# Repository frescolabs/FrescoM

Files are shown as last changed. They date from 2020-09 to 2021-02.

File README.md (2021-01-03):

# FrescoM

Steps to reproduce the project:

1. Order parts from the hardware/components folder
2. 3D print needed parts from the hardware/sources folder
3. Install firmware to your Arduino from the firmware folder
4. Connect your computer with Arduino via serial
5. Install software from software folder

Please file an issue if somthing is not clear.

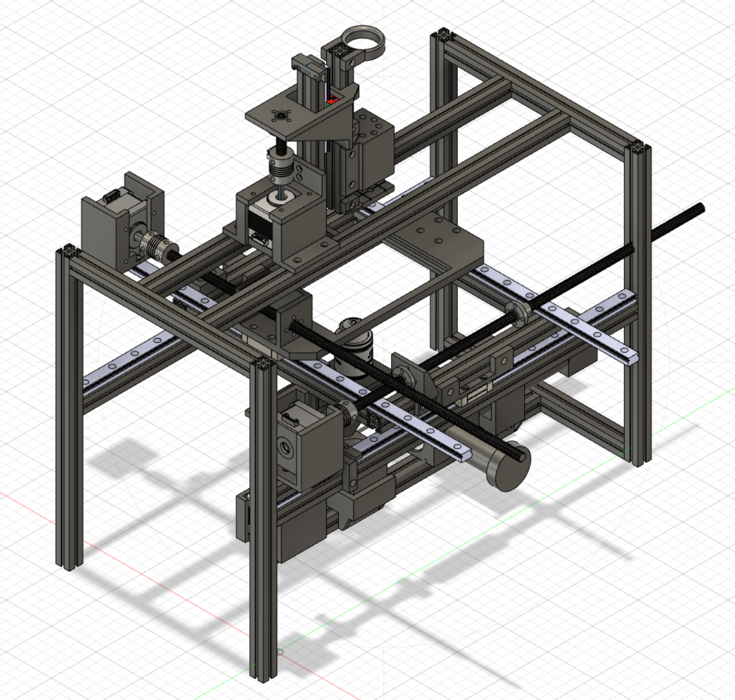
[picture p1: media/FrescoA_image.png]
alt frescoa


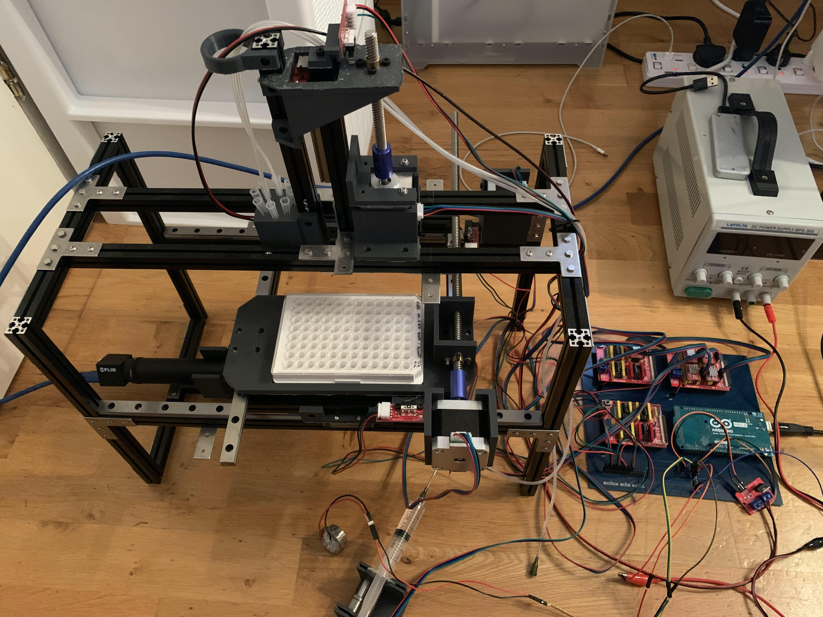
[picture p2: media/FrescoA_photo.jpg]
alt frescoa photo


alt frescoa photo

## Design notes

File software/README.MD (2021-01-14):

# Logic and UI for Fresco

## Set up the project

download anaconda and install conda

run script from "software" folder to install conda environment and some libraries: python 3.8

```bash condainstall.sh```

```conda activate fresco-env  ```

install pip packages for your platform:

```pip install -r mac.txt```

or

```pip install -r windows.txt```

or 

```pip install -r linux.txt```

run

```python main.py```

## Set up in the UI

1. Align top left well with the objective and run "Remember top left position" command

2. Align bottom right well with the objective and run "Remember bottom right position" command

3. Run sync plate coordinates button

![alt frescoa photo](https://github.com/frescolabs/FrescoM/blob/master/media/FrescoA_ux.png?raw=true)

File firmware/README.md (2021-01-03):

Firmware:

Arduino Mega:

You need arduino editor to run it

See all available serial commands here:
https://github.com/frescolabs/FrescoM/blob/master/firmware/FrescoMFirmware/Command.h

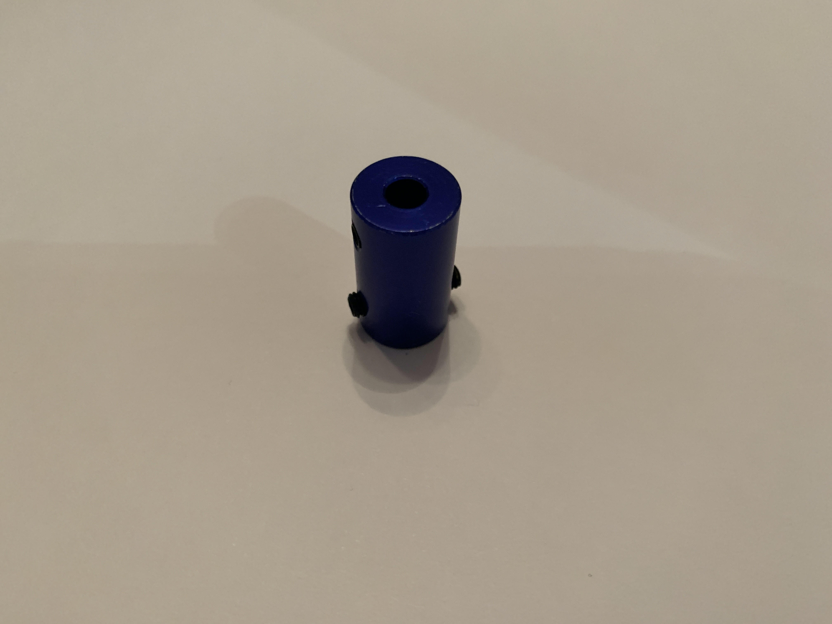
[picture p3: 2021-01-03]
media/Nema_17_adapter.jpg

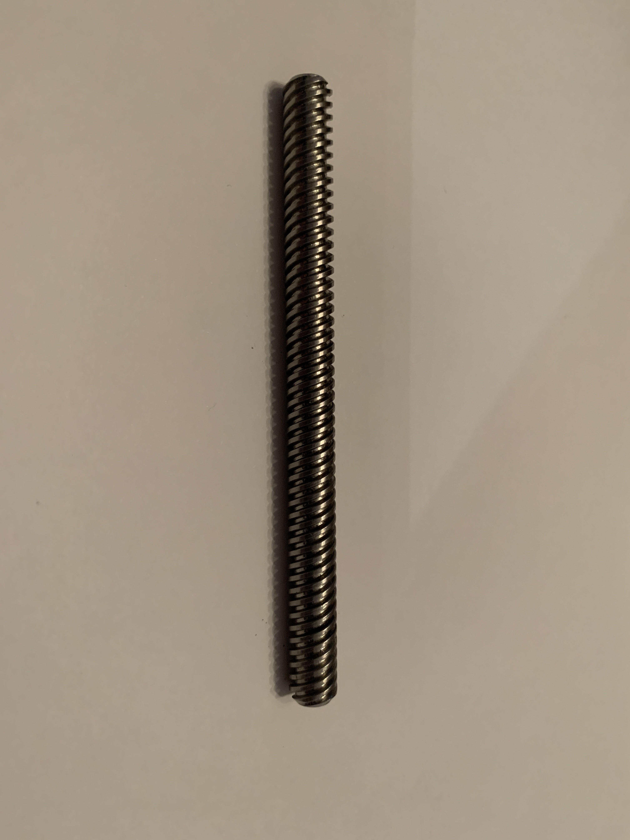
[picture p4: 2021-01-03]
media/Screw.jpg

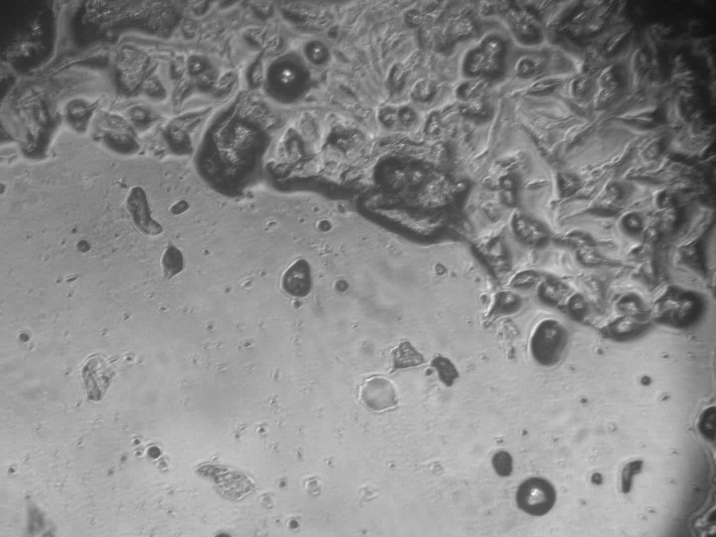
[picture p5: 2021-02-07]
software/1_corner_0.png

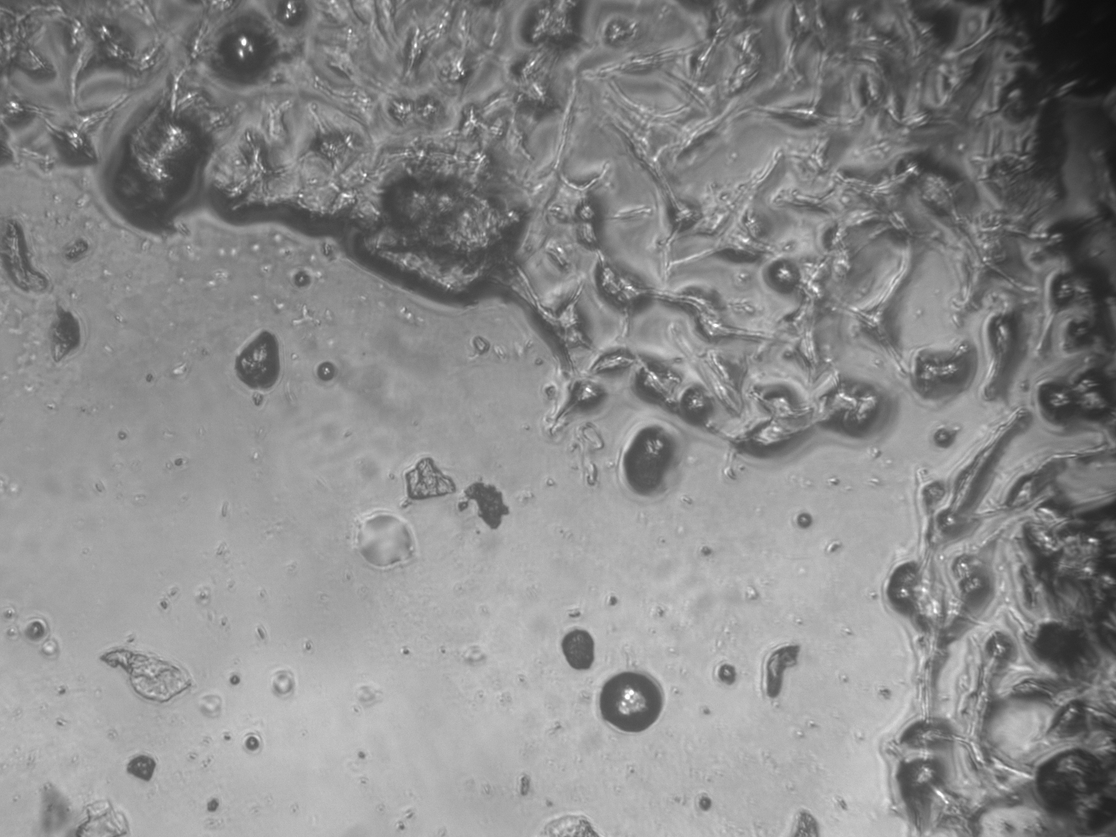
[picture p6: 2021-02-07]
software/1_corner_9.png

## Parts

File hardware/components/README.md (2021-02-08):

List of components for the Hardware part

1. 12  Nema 17 Stepper Motors (+- 22 GBP). 
https://www.amazon.co.uk/Stepper-13N-cm-Holding-Printer-craftsman168/dp/B07H5C5943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

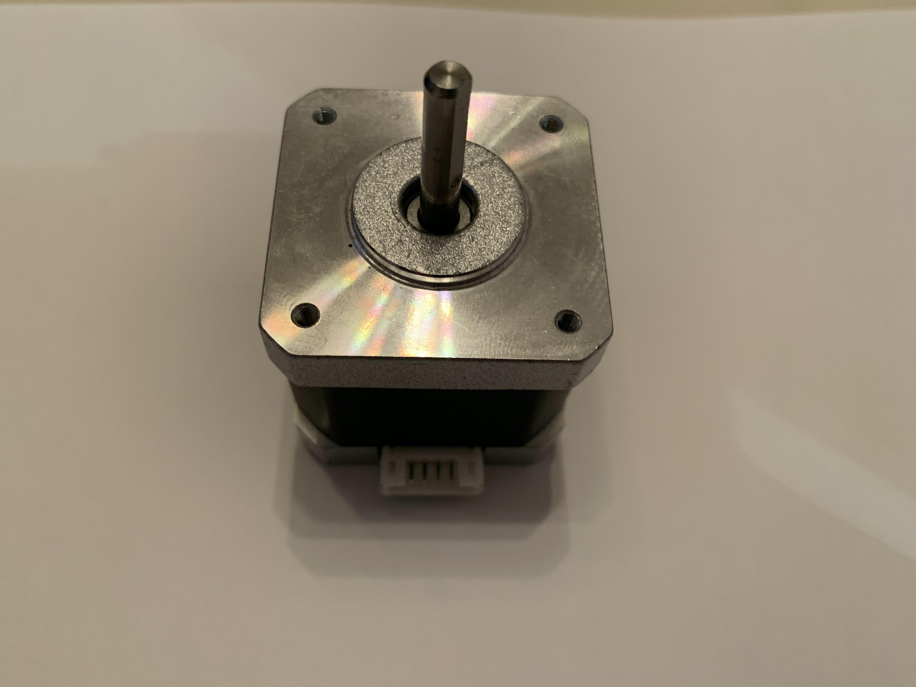
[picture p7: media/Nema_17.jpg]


2. Two 400 mm Linear Guide Rails (+- 44 GBP):
https://www.amazon.co.uk/Miniature-Linear-LML12H-Printer-Machine/dp/B07KK83Y8B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

3. Three 250 mm Linear Guide Rails (+- 44 GBP):
https://www.amazon.co.uk/Accurate-Linear-Guide-Professional-Technical/dp/B07LDBNVTW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

4. One 100 mm Linear Guide Rails
https://www.amazon.co.uk/belupai-100-1000mm-Linear-MGN12H-Sliding/dp/B083LV5PLN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

5. 9 250 mm Screw Rod with Nut (+- 11 GBP).  
https://www.amazon.co.uk/Screw-250mm-Printer-Threaded-Linear/dp/B06WP1WZSY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

6. One 400 mm Screw Rod with Nut (+- 11 GBP):
https://www.amazon.co.uk/Screw-250mm-Printer-Threaded-Linear/dp/B06WRN1DQS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

7. 12 Nema 17 Driver A4988 (+- 13 GBP): 
https://www.amazon.co.uk/Stepper-Stepstick-Headsink-Arduino-Machines/dp/B07B9ZKST7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

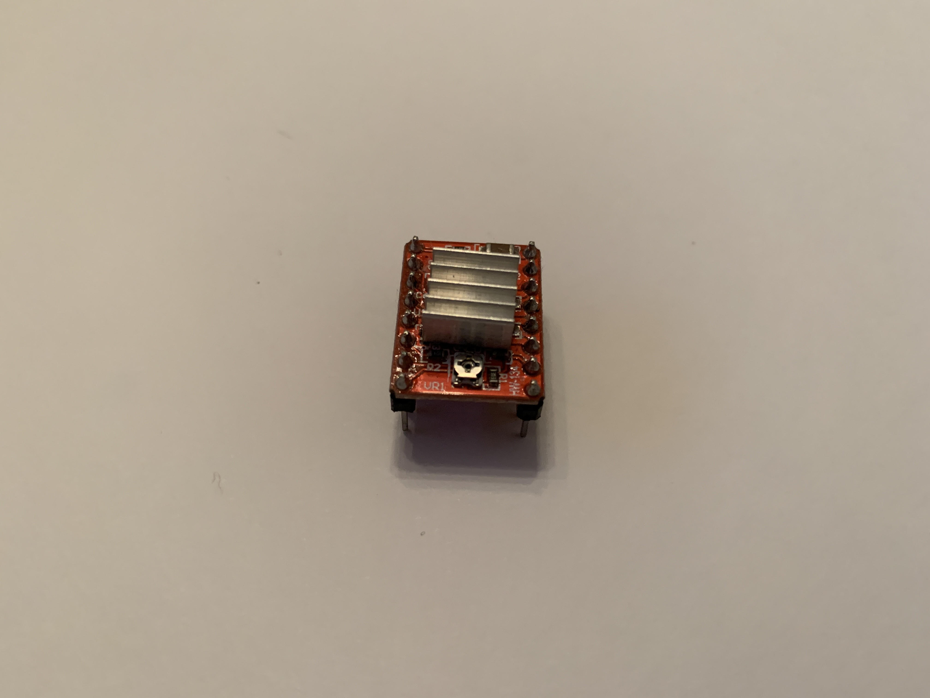
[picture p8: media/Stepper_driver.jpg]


8. 12 Mini Limit Switch 3 pins (+- 8 GBP):
https://www.amazon.co.uk/KingYH-Momentary-Instrument-Communications-Electronic/dp/B07YDFBS5X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

9. One Arduino Mega (+- 42 GBP):
https://www.amazon.co.uk/ARDUINO-MEGA-2560-REV3-A000067/dp/B0046AMGW0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

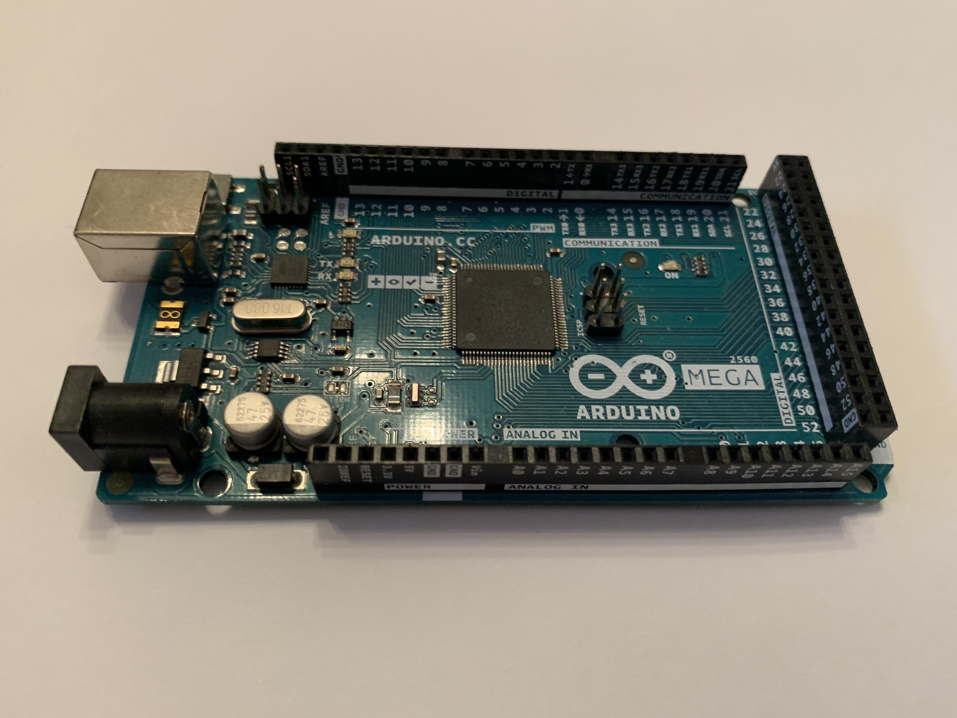
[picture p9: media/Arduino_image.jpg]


10. M3x8/10/15mm Screw and Nut Kit (+- 5 GBP):
https://www.amazon.co.uk/CONNEX-DP8500055-Machine-Screw-Nut/dp/B00B22VHPC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

11. Three CNC shield 
https://www.amazon.co.uk/ARCELI-Engraver-Printer-Expansion-Arduino/dp/B07CQRPFFW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

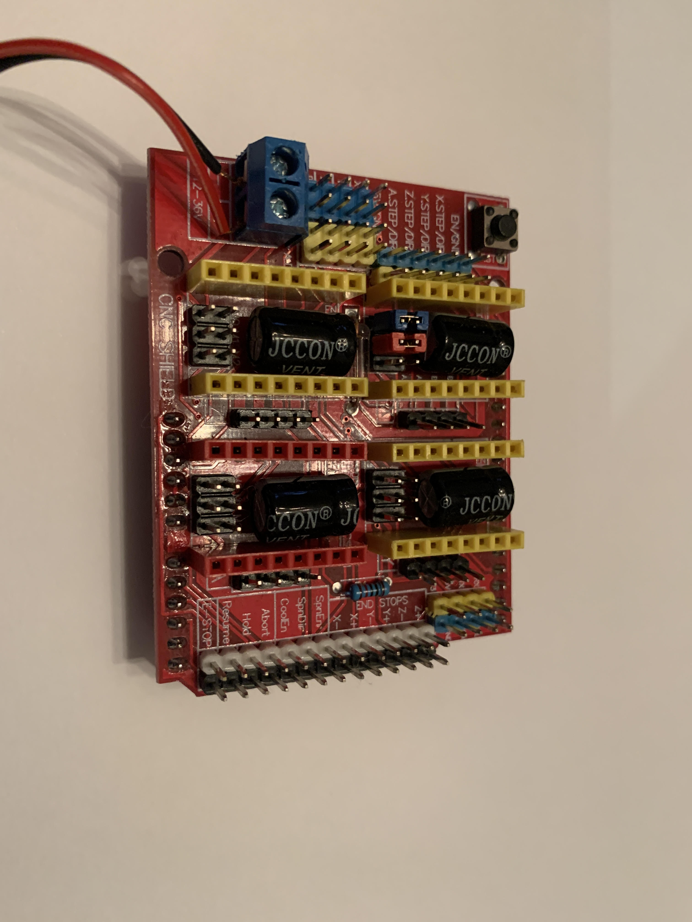
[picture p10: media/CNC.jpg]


12. 8mm mounted bearing
https://www.amazon.co.uk/DealMux-FL08-Self-aligning-Flange-Bearing/dp/B01EZZP2QC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

13. PCB (see Katunin et al. paper)

14. 3d printed components

15. LM8UU linear bearing
https://www.amazon.co.uk/s?k=LM8uu&ref=nb_sb_noss_2

16. 8mm rods
https://www.amazon.co.uk/sourcing-map-Lathe-Round-Length/dp/B07KT3MXV6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

17. 1 X IRF520 MOSFET (+- 3 GBP)
https://www.amazon.co.uk/HCMODU0083-IRF520-MOSFET-Driver-Module/dp/B012ATHAN8

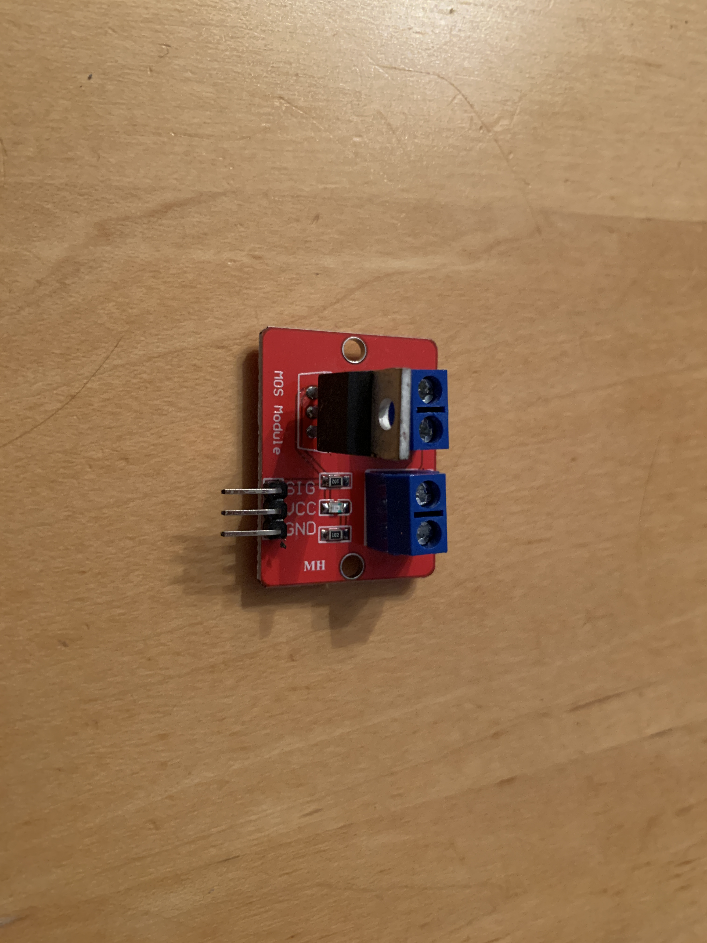
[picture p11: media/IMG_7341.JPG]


18. 1 X RCD-24 Constant Current LED Driver (6 pins)
https://uk.rs-online.com/web/p/led-driver-ics/0472222/

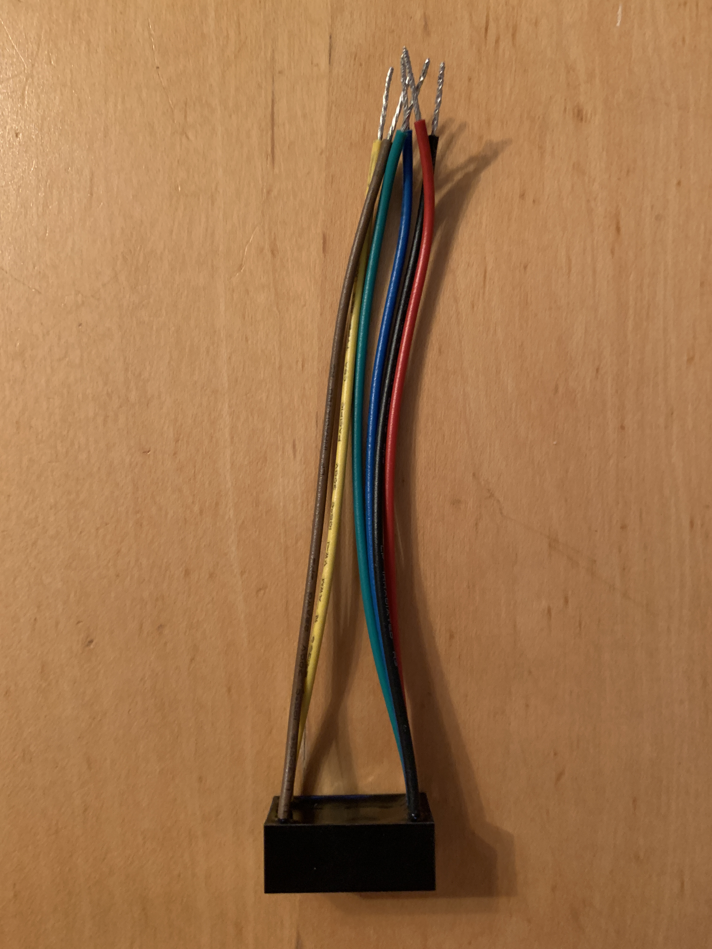
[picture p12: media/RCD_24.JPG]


19. 4 X White LED 3V (+- 5 GBP)
https://www.amazon.co.uk/gp/product/B07FCR8W2H/ref=ppx_yo_dt_b_search_asin_title?ie=UTF8&psc=1

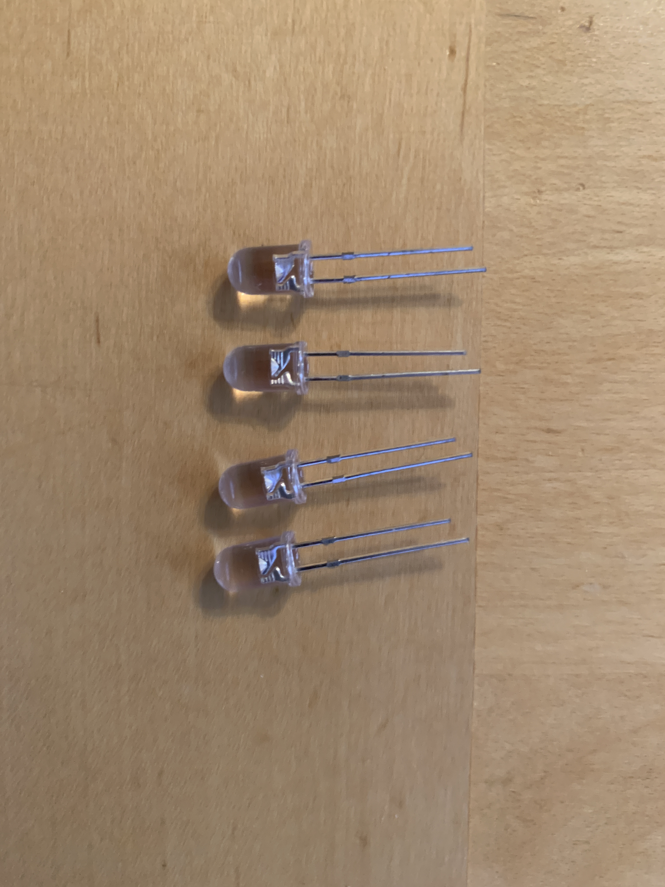
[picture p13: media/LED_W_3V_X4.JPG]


20. MakerBeam XL (+- 111 GBP)
https://www.amazon.co.uk/gp/product/B06XHXJSVL/ref=ppx_yo_dt_b_search_asin_title?ie=UTF8&psc=1

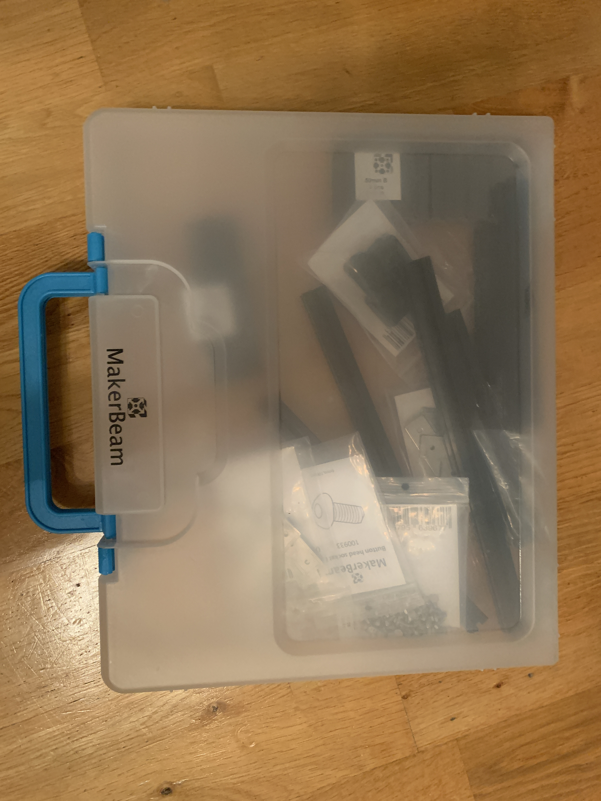
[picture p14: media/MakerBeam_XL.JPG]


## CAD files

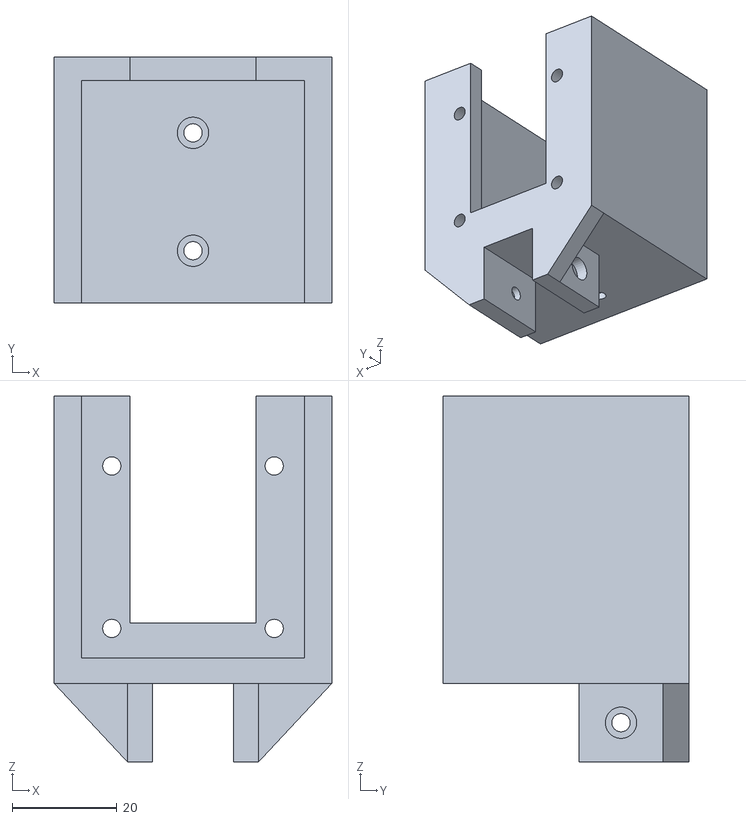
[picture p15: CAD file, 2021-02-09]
hardware/print/x_nema_holder.stl
53.0 x 47.0 x 69.9

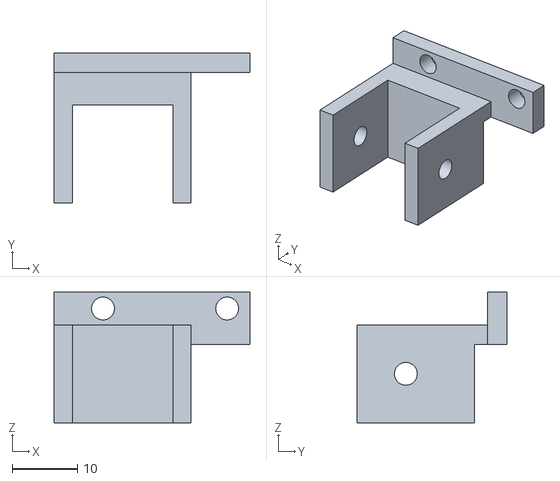
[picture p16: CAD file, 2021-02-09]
hardware/print/z_stopper_holder.stl
30.0 x 23.0 x 20.0

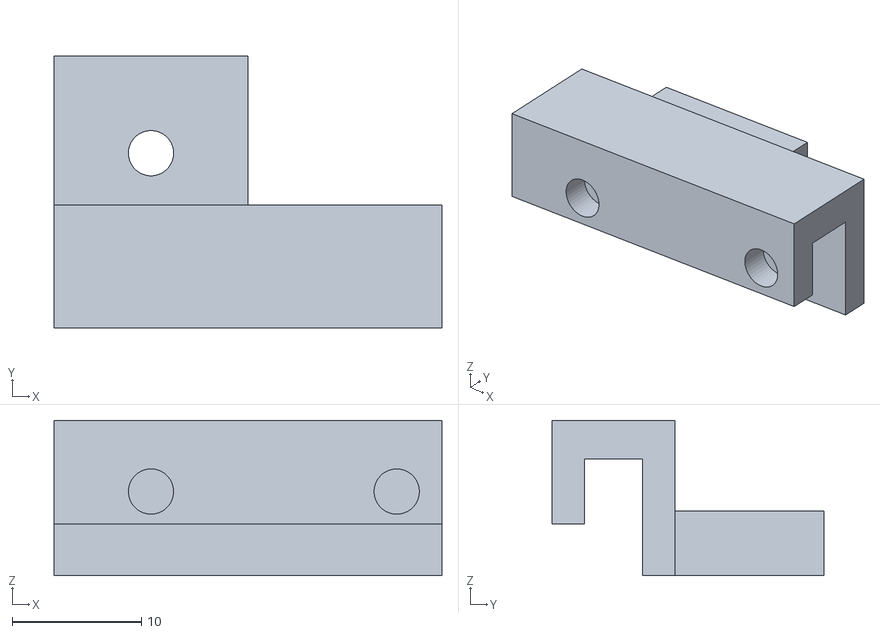
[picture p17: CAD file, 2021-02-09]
hardware/print/manifold_stopper_holder.stl
30.0 x 21.0 x 12.0

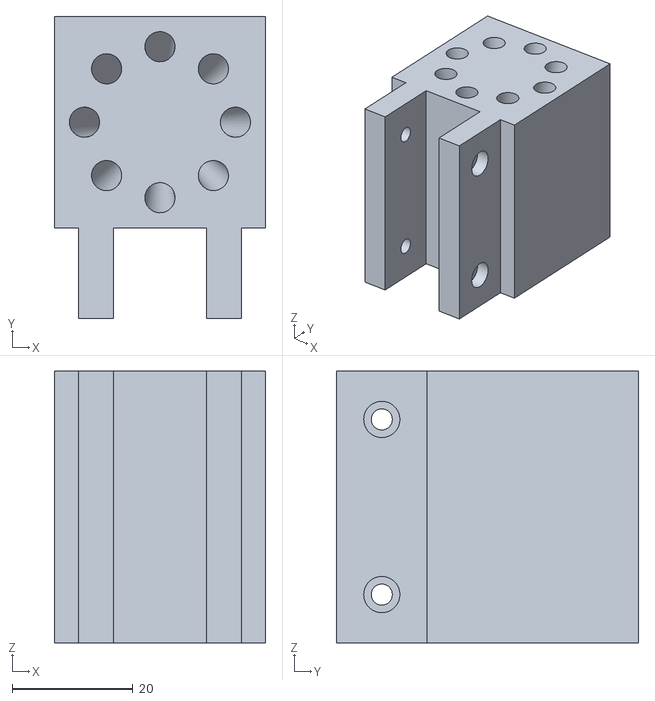
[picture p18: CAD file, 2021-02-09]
hardware/print/manifold_nozels_holder.stl
35.0 x 50.0 x 45.0

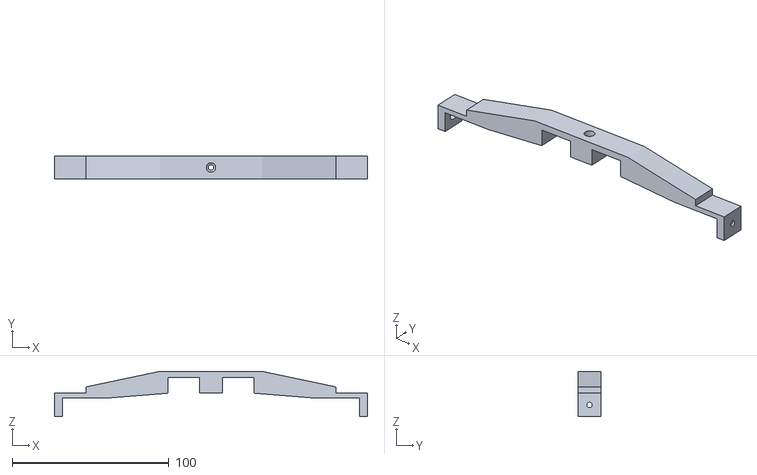
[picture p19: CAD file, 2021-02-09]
hardware/print/z_stabilizer.stl
200.0 x 15.0 x 29.0

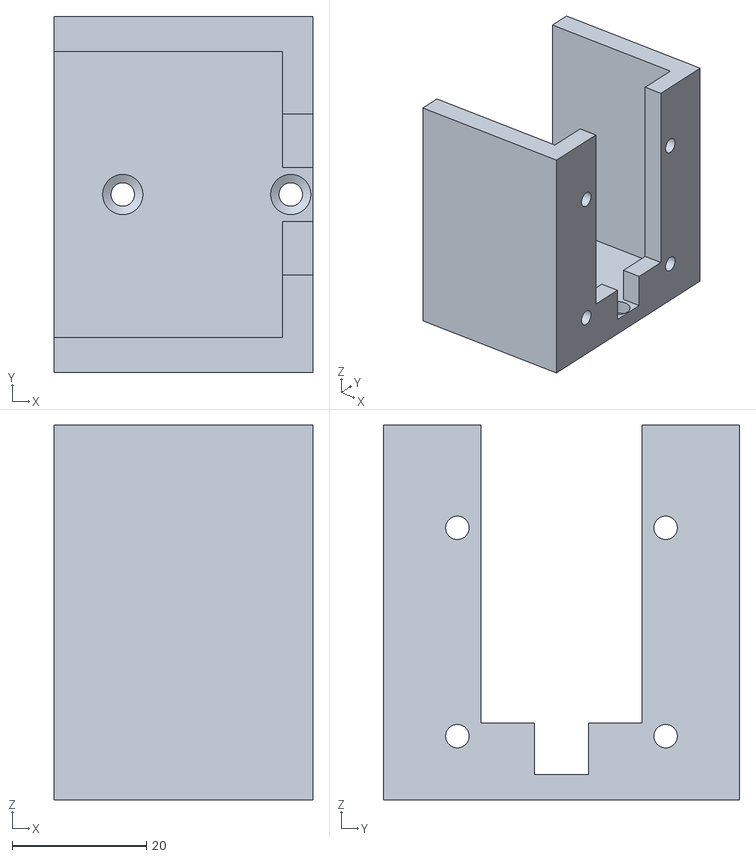
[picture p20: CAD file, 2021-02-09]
hardware/print/y_nema_holder.stl
38.5 x 53.0 x 55.8

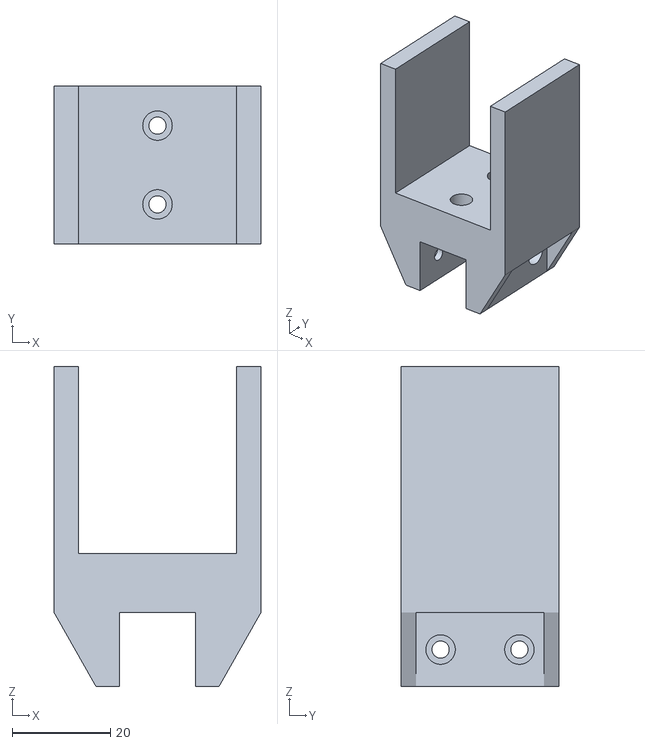
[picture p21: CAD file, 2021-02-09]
hardware/print/microscope_holder.stl
42.0 x 32.0 x 65.0

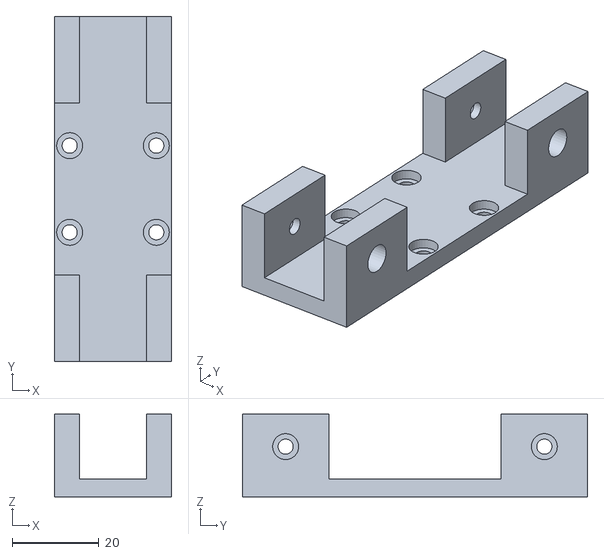
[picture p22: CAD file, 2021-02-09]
hardware/print/y_extrusion_holder_right.stl
27.0 x 79.7 x 19.1

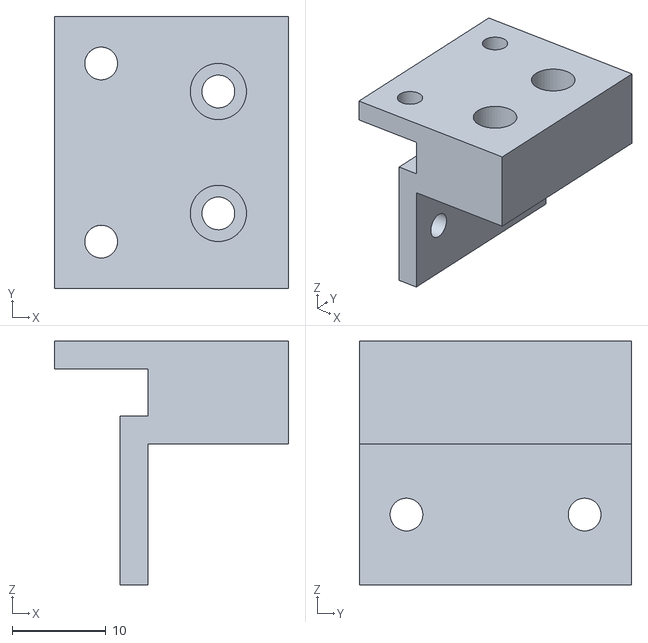
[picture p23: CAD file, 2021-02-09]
hardware/print/y_stopper_holder.stl
25.0 x 29.0 x 26.0

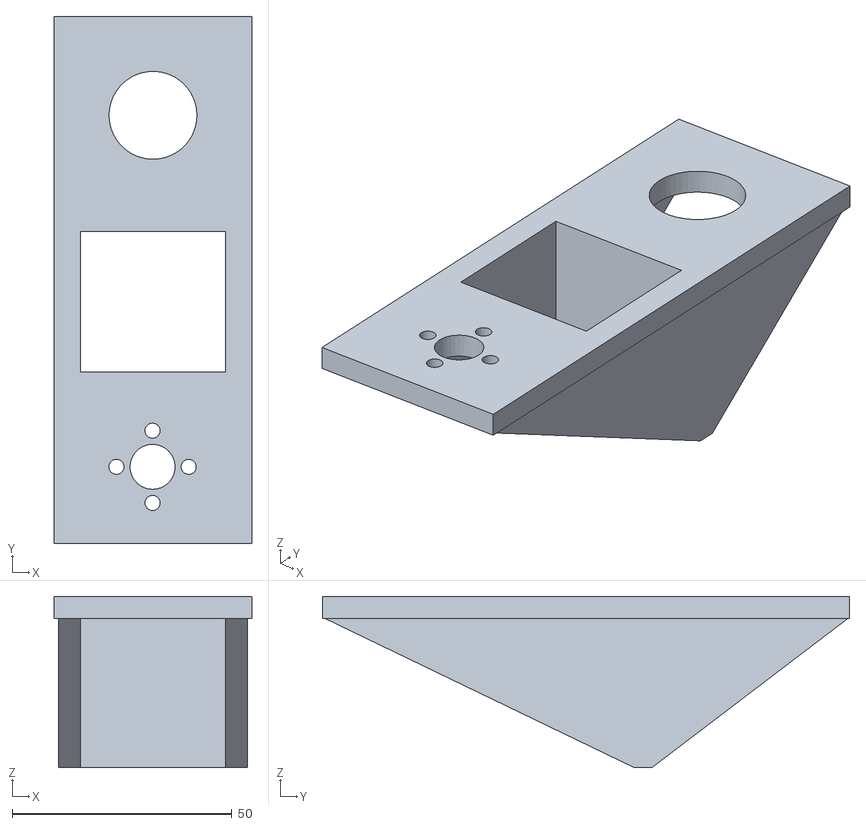
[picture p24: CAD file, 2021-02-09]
hardware/print/objective_holder.stl
45.0 x 120.0 x 39.0

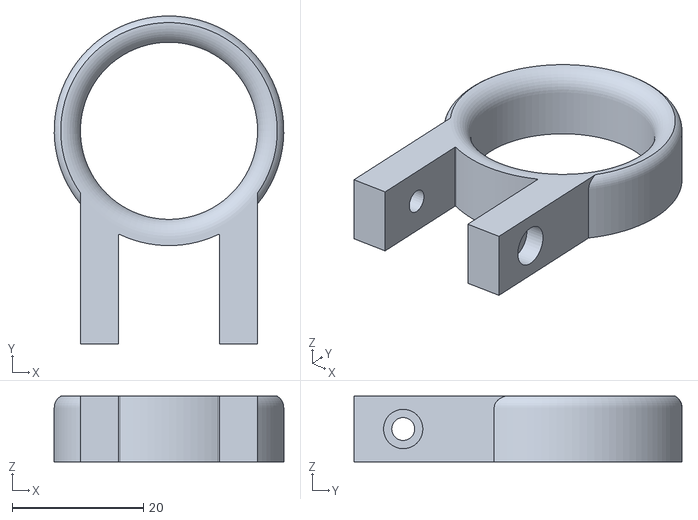
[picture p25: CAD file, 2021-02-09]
hardware/print/manifold_cabels_holder.stl
35.0 x 50.0 x 10.0

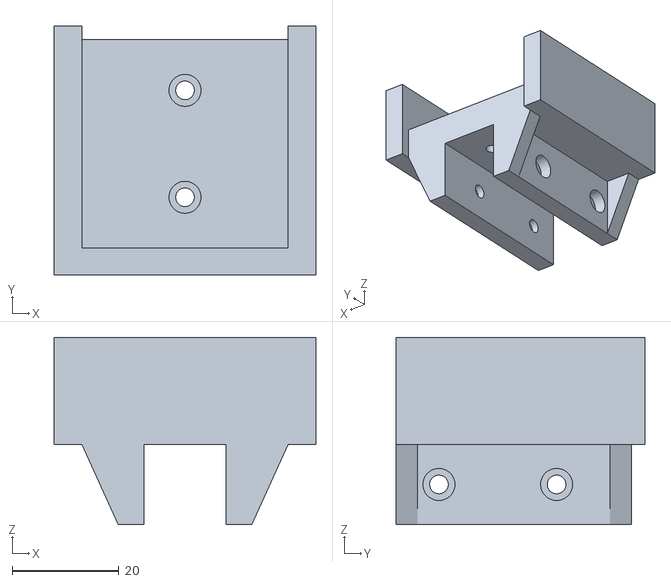
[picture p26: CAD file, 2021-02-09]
hardware/print/microscope_mirror_holder (1).stl
49.0 x 46.5 x 35.0

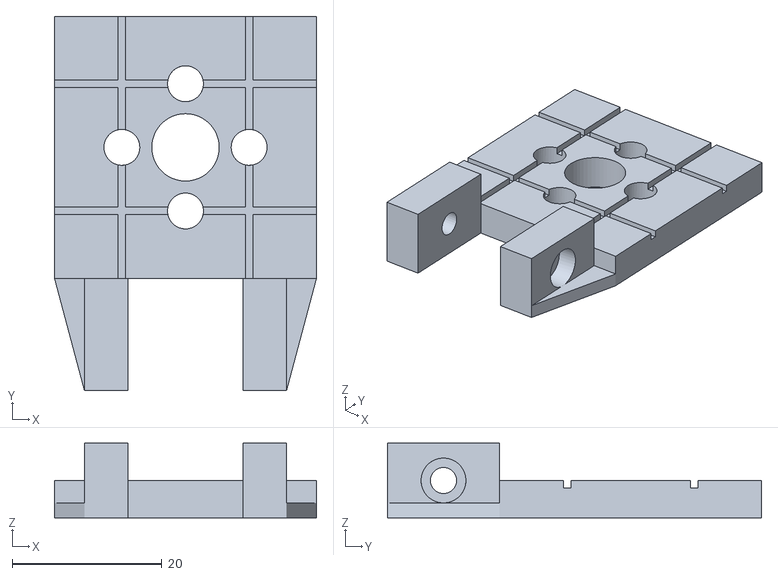
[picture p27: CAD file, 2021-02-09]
hardware/print/manifold_LED_holder.stl
35.0 x 50.0 x 10.0

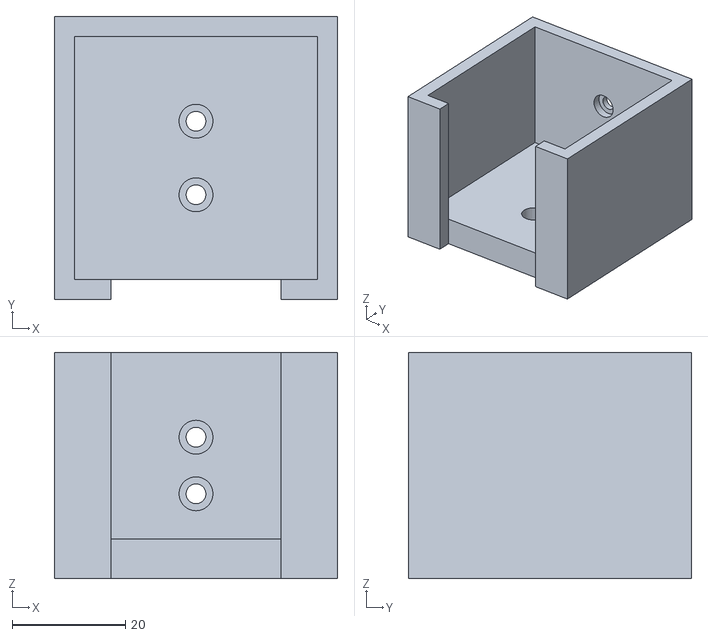
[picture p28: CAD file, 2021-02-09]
hardware/print/z_nema_holder.stl
50.0 x 50.0 x 40.0

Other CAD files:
hardware/print/manifold_extrusion_holder.stl
hardware/print/y_plate_holder.stl
hardware/print/y_extrusion_holder_left.stl
hardware/print/manifold_nema_cap.stl
hardware/print/x_nut_holder.stl
hardware/print/x_stopper_holder.stl
hardware/sources/FrankieNemaPump v3.f3d

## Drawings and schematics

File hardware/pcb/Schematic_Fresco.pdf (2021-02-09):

# ARDUINO

## UNO R3 D⁹D⁸ D⁷

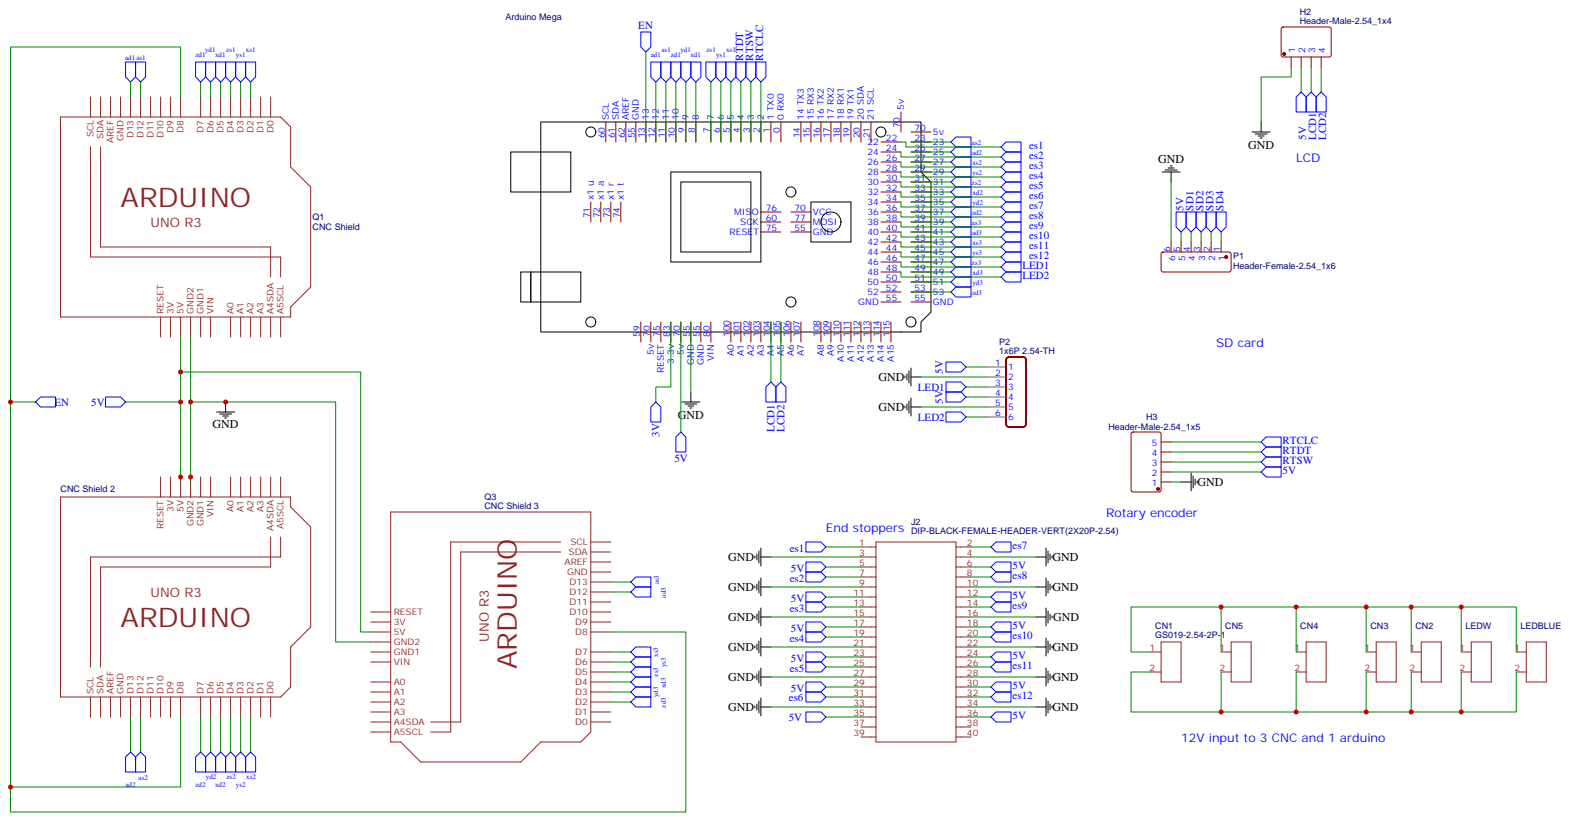
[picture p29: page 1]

DIP-BLACK-FEMALE-HEADER-VERT(2X20P-2.54)

12V input to 3 CNC and 1 arduino

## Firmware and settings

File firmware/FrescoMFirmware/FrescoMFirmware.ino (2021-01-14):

#include "Pins.h" 
#include "EndStopper.h"
#include "Command.h"
#include "EndStopper.h"
#include "FrescoMotor.h"
#include "FrescoXYZ.h"
#include "MotorController.h"
#include "Parser.h"
#include "Manifold.h"

int stepPins[] = {XS1, YS1, ZS1, AS1, XS2, YS2, ZS2, AS2, XS3, YS3, ZS3, AS3};
int dirPins[] = {XD1, YD1, ZD1, AD1, XD2, YD2, ZD2, AD2, XD3, YD3, ZD3, AD3};
int endStopperPins[] = {ES1, ES2, ES3, ES4, ES5, ES6, ES7, ES8, ES9, ES10, ES11, ES12};

void setupPinsModeEndSetEnabled() {
  
  for (int i = 0; i < NUM_MOTORS; i++){
    pinMode(stepPins[i], OUTPUT);
    pinMode(dirPins[i], OUTPUT);
    pinMode(endStopperPins[i], INPUT);
  }

  pinMode(EN, OUTPUT);
  pinMode(LEDW, OUTPUT);
  digitalWrite(EN, LOW);
  digitalWrite(LEDW, LOW);
}

void setupSerial() {
  Serial.begin (250000); 
  Serial.setTimeout(25);
}

FrescoXYZ* frescoXYZ;
Parser* frescoParser;

void setup() {
  setupSerial();

  setupPinsModeEndSetEnabled();
  
  FrescoMotor* xMotor = new FrescoMotor(XS1, XD1);
  FrescoMotor* yMotor = new FrescoMotor(YS1, YD1);
  FrescoMotor* zMotor = new FrescoMotor(ZS1, ZD1);

  EndStopper* xStopper = new EndStopper(ES1);
  EndStopper* yStopper = new EndStopper(ES2);
  EndStopper* zStopper = new EndStopper(ES3);

  MotorController* xMotorController = new MotorController(xMotor, xStopper, true);
  MotorController* yMotorController = new MotorController(yMotor, yStopper, true);
  MotorController* zMotorController = new MotorController(zMotor, zStopper, true);

  FrescoMotor* manifoldZMotor = new FrescoMotor(AS1, AD1);
  EndStopper* manifoldZStopper = new EndStopper(ES4);
  
  MotorController* manifoldZController = new MotorController(manifoldZMotor, manifoldZStopper, false);

  FrescoMotor* pump0Motor = new FrescoMotor(XS2, XD2);
  MotorController* pump0 = new MotorController(pump0Motor, NULL, true);

  FrescoMotor* pump1Motor = new FrescoMotor(YS2, YD2);
  MotorController* pump1 = new MotorController(pump1Motor, NULL, true);

  FrescoMotor* pump2Motor = new FrescoMotor(ZS2, ZD2);
  MotorController* pump2 = new MotorController(pump2Motor, NULL, true);

  FrescoMotor* pump3Motor = new FrescoMotor(AS2, AD2);
  MotorController* pump3 = new MotorController(pump3Motor, NULL, true);

  FrescoMotor* pump4Motor = new FrescoMotor(XS3, XD3);
  MotorController* pump4 = new MotorController(pump4Motor, NULL, true);

  FrescoMotor* pump5Motor = new FrescoMotor(YS3, YD3);
  MotorController* pump5 = new MotorController(pump5Motor, NULL, true);

  FrescoMotor* pump6Motor = new FrescoMotor(ZS3, ZD3);
  MotorController* pump6 = new MotorController(pump6Motor, NULL, true);

  FrescoMotor* pump7Motor = new FrescoMotor(AS3, AD3);
  MotorController* pump7 = new MotorController(pump7Motor, NULL, true);
  
  MotorController *pumps[] = {pump0, pump1, pump2, pump3, pump4, pump5, pump6, pump7};
  Manifold* manifold = new Manifold(manifoldZController, 8, pumps);

  MOSFETLED *whiteLed = new MOSFETLED(LEDW);
  DriverLED *blueLed = new DriverLED(LEDB);

  frescoXYZ = new FrescoXYZ(xMotorController, 
                            yMotorController, 
                            zMotorController, 
                            manifold, 
                            whiteLed,
                            blueLed);
                            
  frescoParser = new Parser();
}

void loop() {
  if (Serial.available() > 0) {
    String line = Serial.readString();
    Command command = frescoParser->parse(line);
    frescoXYZ->perform(command);
  }
}

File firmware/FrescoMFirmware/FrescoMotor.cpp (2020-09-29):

#include "FrescoMotor.h"
#include <Arduino.h>

#define MICROSECONDS_DELAY_BETWEEN_STEPS 100

FrescoMotor::FrescoMotor(int stepPin, int dirPin) {
  this->stepPin = stepPin;
  this->dirPin = dirPin;
  digitalWrite(dirPin, LOW);
  this->setDirection(true);
} 

void FrescoMotor::step() {
  digitalWrite(stepPin, HIGH);
  delayMicroseconds(MICROSECONDS_DELAY_BETWEEN_STEPS);
  digitalWrite(stepPin, LOW);
  delayMicroseconds(MICROSECONDS_DELAY_BETWEEN_STEPS);
}

void FrescoMotor::setDirection(bool direction) {
  this->direction = direction;
  if (this->direction) {
    digitalWrite(dirPin, LOW);
  }
  else {
    digitalWrite(dirPin, HIGH);
  }
}

bool FrescoMotor::getDirection() {
  return direction;
}

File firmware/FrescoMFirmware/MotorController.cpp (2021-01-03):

#include "MotorController.h"

#define REBOUND -1000
#define CURRENT_POSITION_KEY 1

MotorController::MotorController(FrescoMotor* motor, 
                                 EndStopper* stopper,
                                 bool goToZeroDirection) {
  this->motor = motor;
  this->stopper = stopper;
  this->axisLength = -1;
  this->currentPosition = -1;
  this->goToZeroDirection = goToZeroDirection;
  
  if (goToZeroDirection) {
    this->rebound = REBOUND;
  }
  else {
    this->rebound = REBOUND * -1;
  }
  
}

void MotorController::goToPosition(long position) {
  if (currentPosition == -1) {
    // Error case, Zero was not defined
  }
  else {
    this->goDelta(position - this->currentPosition);
  }
}

void MotorController::goDelta(long stepsNumber) {
  if (stepsNumber > 0) {
    this->motor->setDirection(true);
  } else {
    this->motor->setDirection(false);
  }
  long stepsCounter = 0;
  while (stepsCounter < abs(stepsNumber)) {
     motor->step();
     stepsCounter++;
     if (stepsNumber > 0) {
       this->currentPosition++;
     }
     else {
       this->currentPosition--;
     }
  }
}

void MotorController::goToZero() {
  this->motor->setDirection(this->goToZeroDirection);
  while (!stopper->getState()) {
    motor->step();
  }
  goDelta(this->rebound);
  this->setCurrentPositionAsGlobalZero();
}

void MotorController::rememberStartPosition() {
  this->motor->setDirection(true);
  long stepsCounter = 0;
  while (!stopper->getState()) {
    motor->step();
    stepsCounter++;
  }
  goDelta(this->rebound);
  axisStart = stepsCounter;
  this->setCurrentPositionAsGlobalZero();
}

void MotorController::rememberEndPosition() {
  this->motor->setDirection(true);
  long stepsCounter = 0;
  while (!stopper->getState()) {
    motor->step();
    stepsCounter++;
  }
  goDelta(this->rebound);
  axisEnd = stepsCounter;
  this->setCurrentPositionAsGlobalZero();
}

long MotorController::getAxisStart() {
  return this->axisStart;
}

long MotorController::getAxisEnd() {
  return this->axisEnd;
}

long MotorController::setCurrentPositionAsGlobalZero() {
  this->currentPosition = 0;
}

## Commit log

2020-06-29 Pump 3d model
    [FrankieNemaPump v3.f3d]
2021-01-01 Add support for pump and white LED
2021-01-03 support blue LED, white LED refactoring
2021-01-06 Add support for all pumps in firmware
2021-01-12 Update UI code: pumps, leds, segmentation attempt
2021-01-24 removed unused button
2021-02-07 Create a test for not moving plate images, evaluate translation vector
2021-02-08 Image of 4 LED
2021-02-09 Add STLs for printing
    [manifold_LED_holder.stl, manifold_cabels_holder.stl, manifold_extrusion_holder.stl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]
2021-02-09 add gerber
2021-02-09 Nema 17 pump
2021-03-22 fast camera capture, remove simple pyspin
